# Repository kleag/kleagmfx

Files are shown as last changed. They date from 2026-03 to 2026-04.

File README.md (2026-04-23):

# Kleag's MFX

ADS1115
MCP23017
https://github.com/adafruit/Adafruit-MCP23017-Arduino-Library#pin-addressing

KY-040
n°4 on MCP@0x20
    - sw pin B1 (9)
    - but on A0, B0 (0, 8)

Pisound
Raspberry Pi 5 (4 should be OK)

Joystick: ADS.P0, ADS.P1
sudo apt install python3-uinput
sudo nano /etc/modules
uinput

Expression Pedal: ADS.P2

sudo nano /etc/udev/rules.d/99-uinput.rules
KERNEL=="uinput", SUBSYSTEM=="misc", MODE="0660", GROUP="input"
sudo usermod -a -G input $USER

`/boot/firmware/config.txt`:
```
display_auto_detect=1
dtparam=i2c_arm=on
dtparam=spi=on
dtparam=i2c_arm_baudrate=400000
dtoverlay=
dtoverlay=pisound
dtoverlay=vc4-kms-v3d
usb_max_current_enable=1
```

sudo raspi-config
```

Then go to:
`Interface Options → I2C → Enable → Reboot the Pi.`

```bash
sudo apt install -y i2c-tools
```

```bash
sudo i2cdetect -y 1
```

`/home/gael/.config/systemd/user/multieffect.service`
`/home/gael/.config/systemd/user/default.target.wants/multieffect.service -> /home/gael/.config/systemd/user/multieffect.service`

```ini
[Unit]
Description=Start Guitar Multi-Effect Python Script
After=graphical-session.target

[Service]
ExecStart=python /home/gael/multieffects/multieffect.py
WorkingDirectory=/home/gael
Restart=on-failure

[Install]
WantedBy=default.target
```

```bash
journalctl --user-unit multieffect.service
systemctl --user disable multieffect.service
systemctl --user enable multieffect.service
systemctl --user stop multieffect.service
systemctl --user start multieffect.service
```

# Disable wlan power management 
To avoid losing Wifi unexpectedly, disable its power management. Create `/etc/systemd/system/wifi-fix.service`:

```ini
[Unit]
Description=Disable WiFi Power Management
After=network.target

[Service]
Type=oneshot
ExecStart=/sbin/iwconfig wlan0 power off
RemainAfterExit=yes

[Install]
WantedBy=multi-user.target
```

and then enable the new service:
```bash
sudo systemctl enable wifi-fix.service
sudo systemctl start wifi-fix.service
```

# License

Copyright Gaël de Chalendar, 2025-2026.
This source describes Open Hardware and is licensed under the CERN-OHL-
W v2.
You may redistribute and modify this documentation and make products
using it under the terms of the CERN-OHL-W v2 (https:/cern.ch/cern-ohl).
This documentation is distributed WITHOUT ANY EXPRESS OR IMPLIED
WARRANTY, INCLUDING OF MERCHANTABILITY, SATISFACTORY QUALITY
AND FITNESS FOR A PARTICULAR PURPOSE. Please see the CERN-OHL-W v2
for applicable conditions.
Source location: https://github.com/kleag/kleagmfx
As per CERN-OHL-W v2 section 4.1, should You produce hardware based on
these sources, You must maintain the Source Location visible on the
external case of the Kleag's MFX or other product you make using
this documentation.

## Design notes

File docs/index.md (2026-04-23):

# Kleag's MFX

Thi site describes the multieffect pedal I built using a Raspberry Pi, a Pisound sound card, the Guitarix effects software, a repurposed wooden box and various other parts. I am at version 2.2.1 of the pedal, but just beginning the documentation. 

To start with, here are two images of the current version:

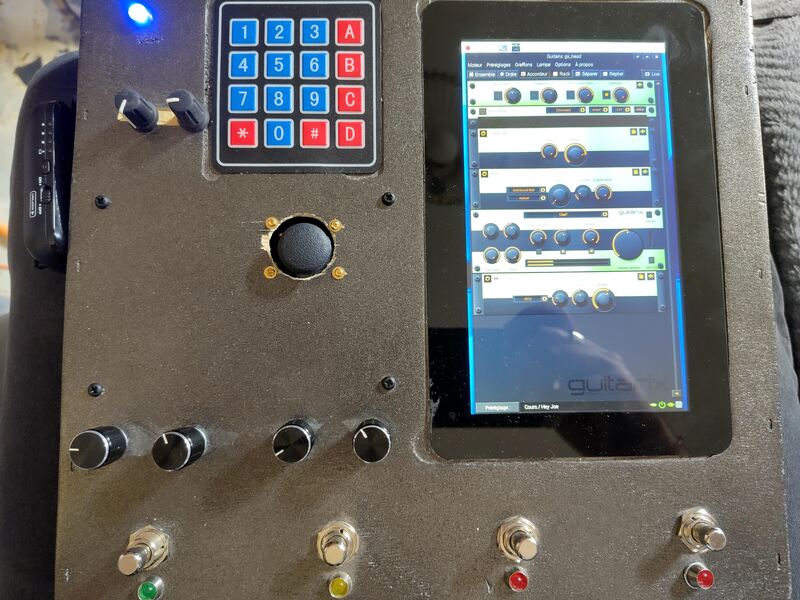
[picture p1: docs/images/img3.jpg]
The Multieffect pedal running


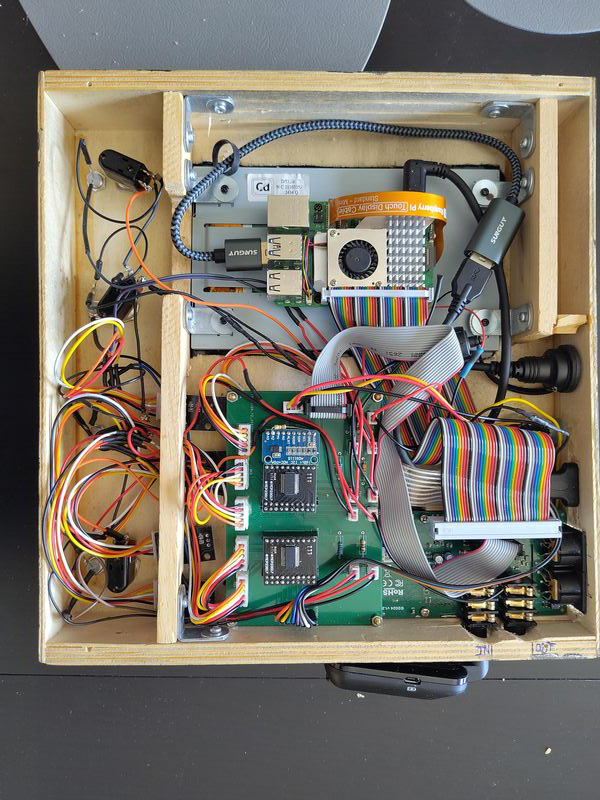
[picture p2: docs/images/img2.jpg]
The interior of the Multieffect pedal


In the future, I will describe the material and software architecture and the history of the making.

ADS1115
MCP23017
https://github.com/adafruit/Adafruit-MCP23017-Arduino-Library#pin-addressing

KY-040
n°4 on MCP@0x20
    - sw pin B1 (9)
    - but on A0, B0 (0, 8)

Pisound
Raspberry Pi 5 (4 should be OK)

Joystick: ADS.P0, ADS.P1
sudo apt install python3-uinput
sudo nano /etc/modules
uinput

Expression Pedal: ADS.P2

sudo nano /etc/udev/rules.d/99-uinput.rules
KERNEL=="uinput", SUBSYSTEM=="misc", MODE="0660", GROUP="input"
sudo usermod -a -G input $USER

`/boot/firmware/config.txt`:
```
display_auto_detect=1
dtparam=i2c_arm=on
dtparam=spi=on
dtparam=i2c_arm_baudrate=400000
dtoverlay=
dtoverlay=pisound
dtoverlay=vc4-kms-v3d
usb_max_current_enable=1
```

sudo raspi-config
```

Then go to:
`Interface Options → I2C → Enable → Reboot the Pi.`

```bash
sudo apt install -y i2c-tools
```

```bash
sudo i2cdetect -y 1
```

`/home/gael/.config/systemd/user/multieffect.service`
`/home/gael/.config/systemd/user/default.target.wants/multieffect.service -> /home/gael/.config/systemd/user/multieffect.service`

```ini
[Unit]
Description=Start Guitar Multi-Effect Python Script
After=graphical-session.target

[Service]
ExecStart=python /home/gael/multieffects/multieffect.py
WorkingDirectory=/home/gael
Restart=on-failure

[Install]
WantedBy=default.target
```

```bash
journalctl --user-unit multieffect.service
systemctl --user disable multieffect.service
systemctl --user enable multieffect.service
systemctl --user stop multieffect.service
systemctl --user start multieffect.service
```

# Disable wlan power management 
To avoid losing Wifi unexpectedly, disable its power management. Create `/etc/systemd/system/wifi-fix.service`:

```ini
[Unit]
Description=Disable WiFi Power Management
After=network.target

[Service]
Type=oneshot
ExecStart=/sbin/iwconfig wlan0 power off
RemainAfterExit=yes

[Install]
WantedBy=multi-user.target
```

and then enable the new service:
```bash
sudo systemctl enable wifi-fix.service
sudo systemctl start wifi-fix.service
```

# License

Copyright Gaël de Chalendar, 2025-2026.
This source describes Open Hardware and is licensed under the CERN-OHL-
W v2.
You may redistribute and modify this documentation and make products
using it under the terms of the CERN-OHL-W v2 (https:/cern.ch/cern-ohl).
This documentation is distributed WITHOUT ANY EXPRESS OR IMPLIED
WARRANTY, INCLUDING OF MERCHANTABILITY, SATISFACTORY QUALITY
AND FITNESS FOR A PARTICULAR PURPOSE. Please see the CERN-OHL-W v2
for applicable conditions.
Source location: https://github.com/kleag/kleagmfx
As per CERN-OHL-W v2 section 4.1, should You produce hardware based on
these sources, You must maintain the Source Location visible on the
external case of the Kleag's MFX or other product you make using
this documentation.

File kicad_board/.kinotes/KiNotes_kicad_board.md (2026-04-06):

# **kicad_board - Design Notes**

## **Overview**
<!-- Brief description of the PCB project -->

## **Schematic Notes**
<!-- Key circuit blocks, design rationale -->

## **Layout Considerations**
<!-- Layer stackup, impedance, keep-outs -->

## **Component Notes**
<!-- Click on designators like R1, C5, U3 to highlight on PCB -->

## **Power Distribution**
<!-- Power rails, decoupling strategy -->

## **Signal Integrity**
<!-- Critical nets, routing constraints -->

## **References**
<!-- Datasheets, application notes, calculations -->

---
*KiNotes - PCBtools.xyz*

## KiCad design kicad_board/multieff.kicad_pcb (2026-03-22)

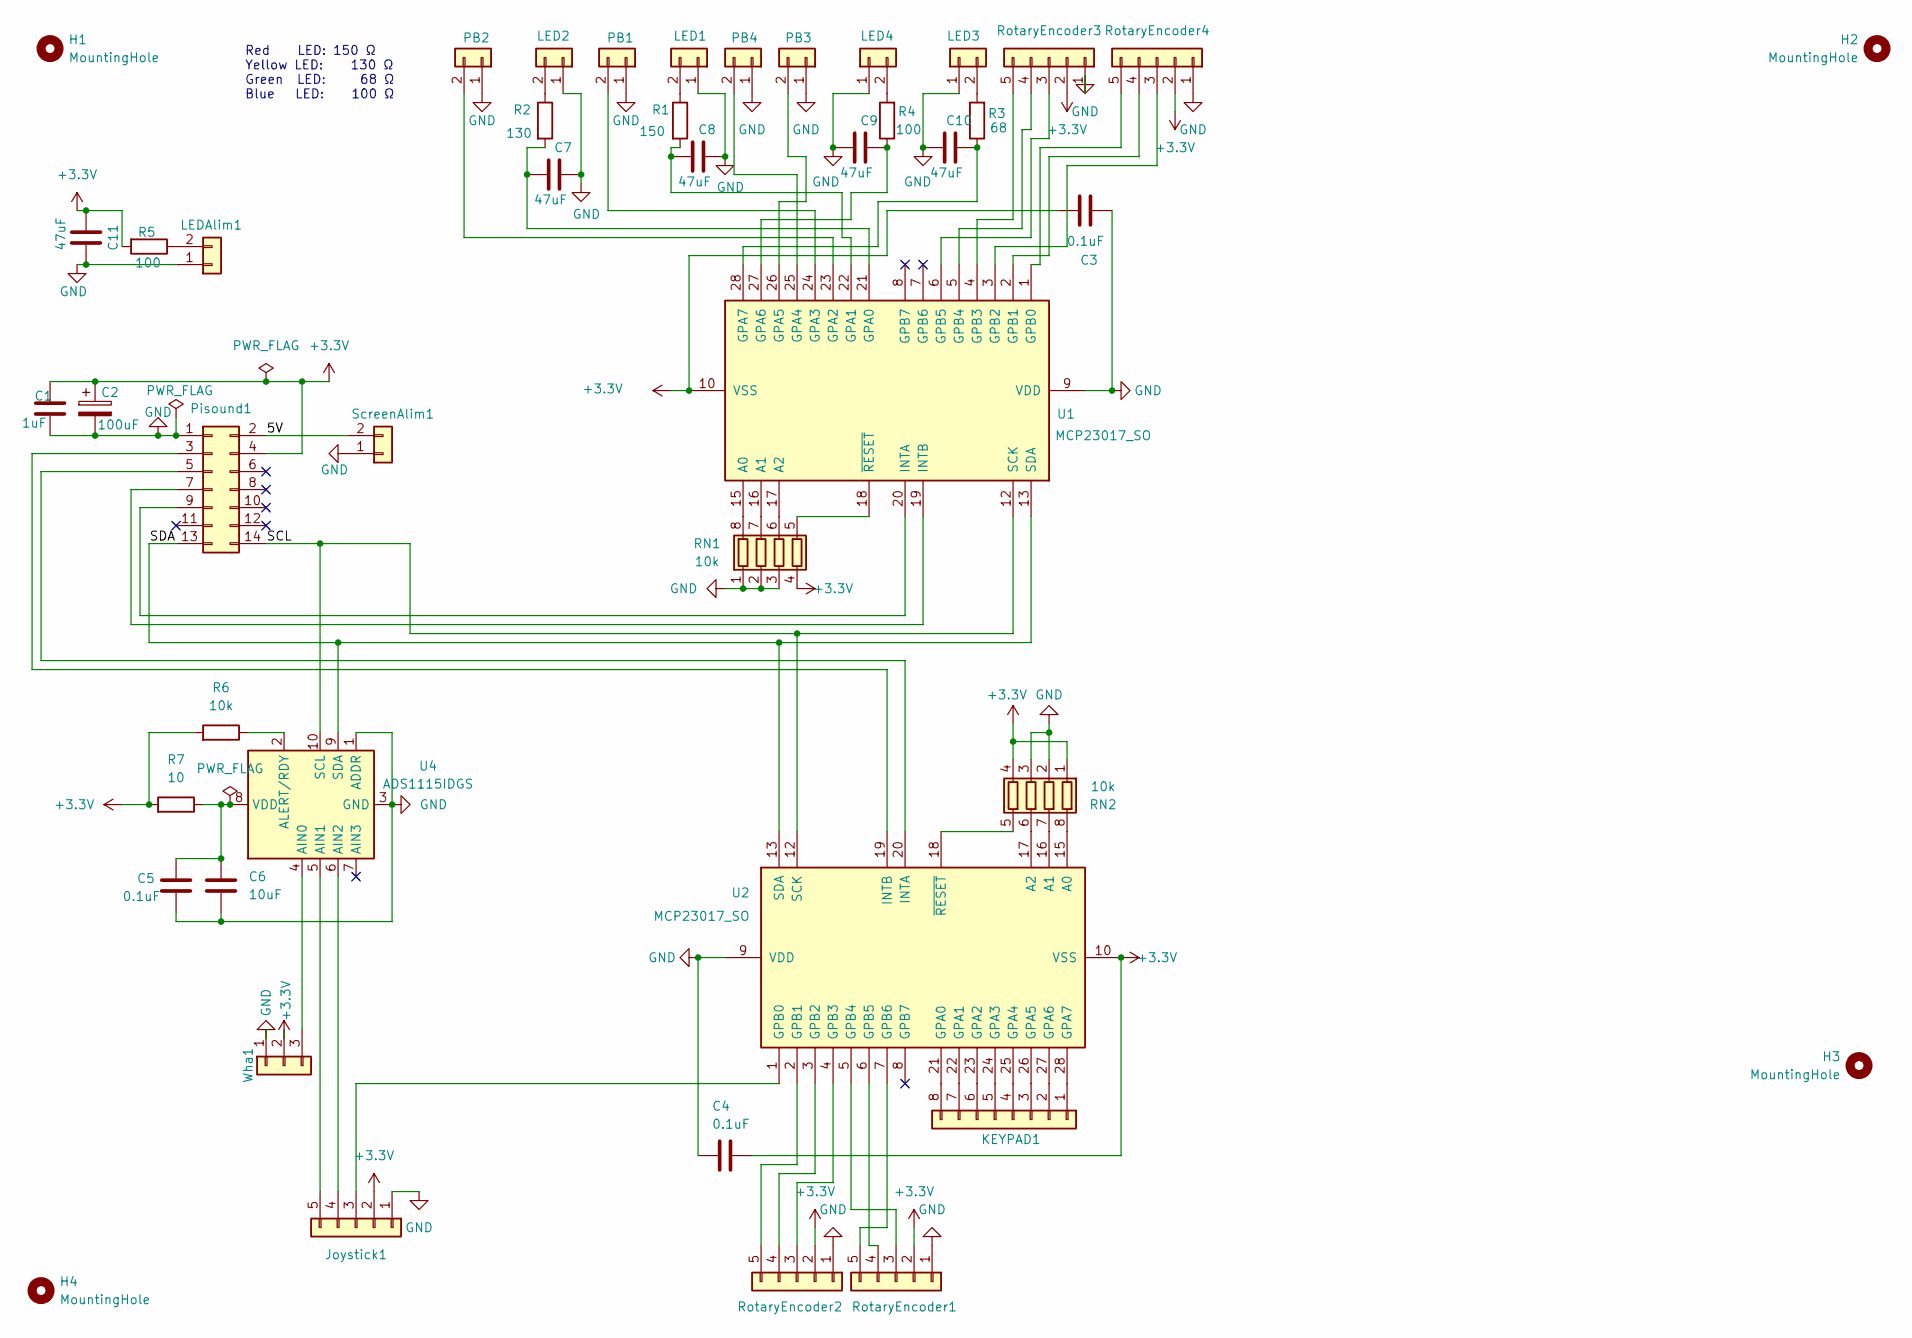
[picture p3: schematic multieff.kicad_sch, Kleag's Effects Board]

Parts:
C1: 1uF; C_0805_2012Metric
C2: 100uF; CP_Elec_6.3x5.4
C3, C4: 0.1uF; C_1206_3216Metric
C5: 0.1uF; C_0805_2012Metric
C6: 10uF; C_0805_2012Metric
C7, C8, C9, C10, C11: 47uF; C_0805_2012Metric
H1, H2, H3, H4: MountingHole; MountingHole_3.2mm_M3
J1: Wha1; JST_XH_B3B-XH-AM_1x03_P2.50mm_Vertical
Joystick1: Conn_01x05; JST_XH_B5B-XH-AM_1x05_P2.50mm_Vertical
KEYPAD1: Conn_01x08; PinSocket_1x08_P2.54mm_Vertical
LED1, LED2, LED3, LED4: Conn_01x02; JST_XH_B2B-XH-AM_1x02_P2.50mm_Vertical
LEDAlim1: Conn_01x02; JST_XH_B2B-XH-AM_1x02_P2.50mm_Vertical
PB1, PB2, PB3, PB4: Conn_01x02; JST_XH_B2B-XH-AM_1x02_P2.50mm_Vertical
Pisound1: Conn_02x07_Odd_Even; IDC-Header_2x07_P2.54mm_Vertical_SMD
R1: 150; R_1206_3216Metric_Pad1.30x1.75mm_HandSolder
R2: 130; R_1206_3216Metric_Pad1.30x1.75mm_HandSolder
R3: 68; R_1206_3216Metric_Pad1.30x1.75mm_HandSolder
R4, R5: 100; R_1206_3216Metric_Pad1.30x1.75mm_HandSolder
R6: 10k; R_0612_1632Metric
R7: 10; R_0612_1632Metric
RN1, RN2: 10k; R_Array_Convex_4x1206
RotaryEncoder1, RotaryEncoder2, RotaryEncoder3, RotaryEncoder4: Conn_01x05; JST_XH_B5B-XH-AM_1x05_P2.50mm_Vertical
ScreenAlim1: Conn_01x02; JST_XH_B2B-XH-AM_1x02_P2.50mm_Vertical
U1, U2: MCP23017_SO; SOIC-28W_7.5x17.9mm_P1.27mm
U4: ADS1115IDGS; TSSOP-10_3x3mm_P0.5mm

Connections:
+3.3V: C1.1, C2.1, C3.2, C4.2, C11.1, J1.2, Joystick1.2, Pisound1.4, R5.2, R6.1, R7.1, RN1.4 (R4.1), RN2.1 (R1.1), RN2.4 (R4.1), RotaryEncoder1.2, RotaryEncoder2.2, RotaryEncoder3.2, RotaryEncoder4.2, U1.10 (VSS), U2.10 (VSS)
/5V: Pisound1.2, ScreenAlim1.2
/SCL: Pisound1.14, U1.12 (SCK), U2.12 (SCK), U4.10 (SCL)
/SDA: Pisound1.13, U1.13 (SDA), U2.13 (SDA), U4.9 (SDA)
GND: C1.2, C2.2, C3.1, C4.1, C5.2, C6.2, C7.2, C8.2, C9.1, C10.1, C11.2, J1.1, Joystick1.1, LED1.1, LED2.1, LED3.1, LED4.1, LEDAlim1.1, PB1.1, PB2.1, PB3.1, PB4.1, Pisound1.1, RN1.1 (R1.1), RN1.2 (R2.1), RN1.3 (R3.1), RN2.2 (R2.1), RN2.3 (R3.1), RotaryEncoder1.1, RotaryEncoder2.1, RotaryEncoder3.1, RotaryEncoder4.1, ScreenAlim1.1, U1.9 (VDD), U2.9 (VDD), U4.1 (ADDR), U4.3 (GND)
unnamed: J1.3, U4.4 (AIN0)
unnamed: Joystick1.3, U2.1 (GPB0)
unnamed: Joystick1.4, U4.6 (AIN2)
unnamed: Joystick1.5, U4.5 (AIN1)
unnamed: KEYPAD1.1, U2.28 (GPA7)
unnamed: KEYPAD1.2, U2.27 (GPA6)
unnamed: KEYPAD1.3, U2.26 (GPA5)
unnamed: KEYPAD1.4, U2.25 (GPA4)
unnamed: KEYPAD1.5, U2.24 (GPA3)
unnamed: KEYPAD1.6, U2.23 (GPA2)
unnamed: KEYPAD1.7, U2.22 (GPA1)
unnamed: KEYPAD1.8, U2.21 (GPA0)
unnamed: LED1.2, R1.1
unnamed: LED2.2, R2.1
unnamed: LED3.2, R3.2
unnamed: LED4.2, R4.2
unnamed: LEDAlim1.2, R5.1
unnamed: PB1.2, U1.24 (GPA3)
unnamed: PB2.2, U1.23 (GPA2)
unnamed: PB3.2, U1.26 (GPA5)
unnamed: PB4.2, U1.25 (GPA4)
unnamed: Pisound1.3, U2.19 (INTB)
unnamed: Pisound1.5, U2.20 (INTA)
unnamed: Pisound1.7, U1.19 (INTB)
unnamed: Pisound1.9, U1.20 (INTA)
unnamed: RN1.8 (R1.2), U1.15 (A0)
unnamed: RN1.7 (R2.2), U1.16 (A1)
unnamed: RN1.6 (R3.2), U1.17 (A2)
unnamed: RN1.5 (R4.2), U1.18 (~RESET)
unnamed: RN2.8 (R1.2), U2.15 (A0)
unnamed: RN2.7 (R2.2), U2.16 (A1)
unnamed: RN2.6 (R3.2), U2.17 (A2)
unnamed: RN2.5 (R4.2), U2.18 (~RESET)
unnamed: RotaryEncoder1.3, U2.5 (GPB4)
unnamed: RotaryEncoder1.4, U2.6 (GPB5)
unnamed: RotaryEncoder1.5, U2.7 (GPB6)
unnamed: RotaryEncoder2.3, U2.4 (GPB3)
unnamed: RotaryEncoder2.4, U2.3 (GPB2)
unnamed: RotaryEncoder2.5, U2.2 (GPB1)
unnamed: RotaryEncoder3.3, U1.6 (GPB5)
unnamed: RotaryEncoder3.4, U1.5 (GPB4)
unnamed: RotaryEncoder3.5, U1.4 (GPB3)
unnamed: RotaryEncoder4.3, U1.3 (GPB2)
unnamed: RotaryEncoder4.4, U1.2 (GPB1)
unnamed: RotaryEncoder4.5, U1.1 (GPB0)
unnamed: C7.1, R2.2, U1.21 (GPA0)
unnamed: C8.1, R1.2, U1.22 (GPA1)
unnamed: C9.2, R4.1, U1.27 (GPA6)
unnamed: C10.2, R3.1, U1.28 (GPA7)
unnamed: R6.2, U4.2 (ALERT/RDY)
unnamed: C5.1, C6.1, R7.2, U4.8 (VDD)

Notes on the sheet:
Red LED: 150 Ω Yellow LED: 130 Ω Green LED: 68 Ω Blue LED: 100 Ω

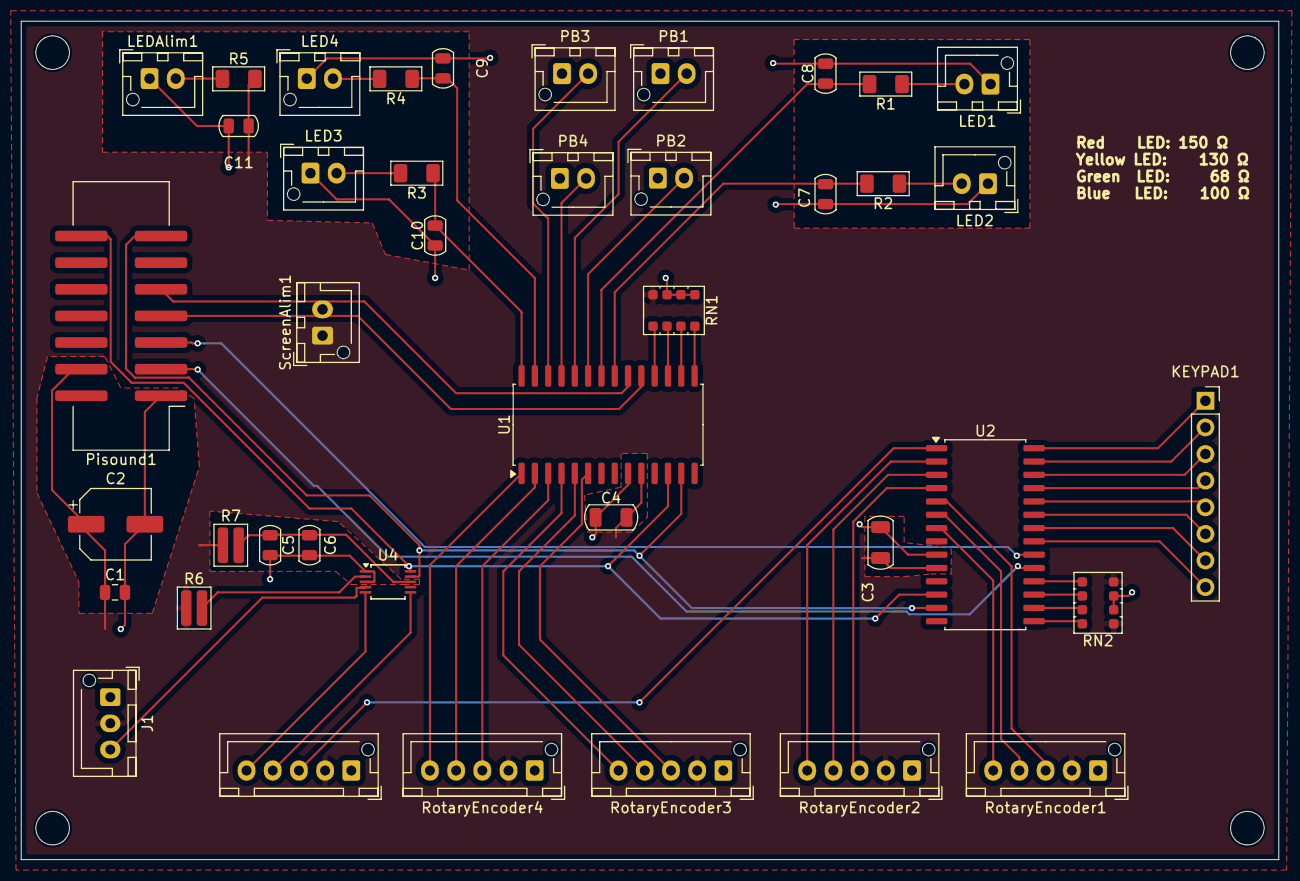
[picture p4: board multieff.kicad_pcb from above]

Board: 2 copper layers, 120.0 x 80.0 mm, 45 parts (0 on the bottom side), 56 nets.

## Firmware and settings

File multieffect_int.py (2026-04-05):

#!/usr/bin/env python3
import adafruit_ads1x15.ads1115 as ADS
import board
import busio
import digitalio
import math
import queue
import time
import uinput
import mido
import logging
import subprocess
import threading

from adafruit_ads1x15.analog_in import AnalogIn
from adafruit_mcp230xx.mcp23017 import MCP23017
from digitalio import Direction, Pull
from gpiozero import Button as GpioZeroButton, LED as GpioZeroLED
from signal import pause

from expression_pedal import ExpressionPedal
from joystick import Joystick
from keypad import KeyPad
from mcp_button import MCPButton
from mcp_led import MCPLed
from rotary_encoder import RotaryEncoder

logger = logging.getLogger(__name__)
logging.basicConfig(level=logging.DEBUG, force=True)

# --- CONFIGURATION ---
SWITCH_CC = 64  # MIDI CC number for effect toggles
ENCODER_CC_NUMBERS = [20, 21, 22, 23]  # MIDI CC for encoders

# Keypad/Power LED (Keep original GPIO)
POWER_LED_PIN = 11

# MCP23017 1 Button/LED Map
BUTTON_PINS_MAP = [(1, 14), (1, 15), (1, 6), (1, 7)] # B6, B7, A6, A7
LED_PINS_MAP = [(1, 13), (1, 12), (1, 4), (1, 5)] # B5, B4, A4, A5

# --- MIDI/ENCODER LOGIC ---
effect_states = [False] * 4 # Global state for MIDI toggles

def send_cc(cc, value):
    msg = mido.Message('control_change', control=cc, value=value)
    midi_out.send(msg)

# --- BUTTON HANDLERS ---
def handle_effect_toggle(idx):
    # logger.info(f"handle_effect_toggle {idx}")
    effect_states[idx] = not effect_states[idx]
    if leds[idx] is not None:
        leds[idx].value = effect_states[idx]
    send_cc(SWITCH_CC + idx, 127 if effect_states[idx] else 0)
    # logger.info(f"Button {idx} pressed. State: {effect_states[idx]}")


def reset():
    logger.info("reset")
    for i in range(len(effect_states)):
        effect_states[i] = False
        if leds[i] is not None:
            leds[i].value = False

# --- THREADS ---

def midi_input_thread():
    # logger.info("Listening for incoming MIDI messages...")
    for msg in midi_in:
        if msg.type == 'control_change':
            # logger.info(f"midi_input_thread received: {msg}")
            # Update Effect States (SWITCH_CC)
            if SWITCH_CC <= msg.control <= SWITCH_CC + 3:
                idx = msg.control - SWITCH_CC
                new_state = msg.value > 0

                # Only update if the state actually changed to avoid flickering
                if effect_states[idx] != new_state:
                    effect_states[idx] = new_state
                    if leds[idx] is not None:
                        leds[idx].value = new_state
                # logger.debug(f"Sync: LED {idx} set to {new_state} via MIDI")
            # Update Encoder CC Value if received externally
            if msg.control in ENCODER_CC_NUMBERS:
                for encoders in [encoders_mcp1, encoders_mcp2]:
                    for enc in encoders:
                        if enc.cc == msg.control:
                            enc.update_from_midi(msg.value)
                            break

def buttons_thread():
    while True:
        # MCP Button Scan
        for i, btn in enumerate(buttons):
            btn.check(i)
        time.sleep(0.01)

# --- Main Thread Logic ---
def main_thread_loop():
    # logger.info("\n[Main Thread] Starting queue processor...")

    while True:
        while not task_queue.empty():
            try:
                func, args = task_queue.get(timeout=0.1)
                if func == "reset":
                    reset(*args)

                task_queue.task_done()
            except queue.Empty:
                # This happens if the queue is temporarily empty
                pass
        time.sleep(0.001)

def link_pipewire_ports():
    try:
        # Link Script -> Guitarix
        subprocess.run(['pw-link', 'Midi-Bridge:RtMidiOut Client:(capture_0) KleagMFX', 'gx_head_amp:midi_in_1'], check=False)
        # Link Guitarix -> Script
        subprocess.run(['pw-link', 'gx_head_amp:midi_out_1', 'Midi-Bridge:RtMidiIn Client:(playback_0) KleagMFX'], check=False)
        logger.info("PipeWire MIDI ports linked successfully.")
    except Exception as e:
        logger.error(f"Failed to link PipeWire ports: {e}")


# --- MIDI SETUP ---
midi_out = mido.open_output('KleagMFX', virtual=True)
midi_in = mido.open_input('KleagMFX', virtual=True)

# --- HARDWARE INITIALIZATION ---
i2c = busio.I2C(board.SCL, board.SDA)
i2c_lock = threading.Lock()

# ADS1115 for Joystick (kept as requested)
ads = ADS.ADS1115(i2c)

# MCP23017
mcp1 = MCP23017(i2c, address=0x20)
mcp2 = MCP23017(i2c, address=0x21)
MCP_MAP = {1: mcp1, 2: mcp2}

# --- Configuration of Interruption pins ---
int_mcp1 = digitalio.DigitalInOut(board.D22) # Pin pisound 7
int_mcp2 = digitalio.DigitalInOut(board.D5)  # Pin pisound 5
for pin in [int_mcp1, int_mcp2]:
    pin.direction = digitalio.Direction.INPUT
    pin.pull = digitalio.Pull.UP

for m in [mcp1, mcp2]:
    m.interrupt_configuration = 0x40 # Mode Mirror : INTA/B linked
    # Activate interruptions on pins used
    # MCP1 : A0, A1, A2, A3 (0x0F) et B0, B1 (0x03)
    # MCP2 : B2-B7 (0xFC)
    if m == mcp1:
        m._write_u8(0x04, 0x0F) # GPINTENA
        m._write_u8(0x05, 0x03) # GPINTENB
    else:
        m._write_u8(0x04, 0x00) # GPINTENA (rien sur port A)
        m._write_u8(0x05, 0xFC) # GPINTENB (B2 à B7)


# Power LED
power_led = mcp1.get_pin(POWER_LED_PIN)
power_led.direction = Direction.OUTPUT
power_led.value = True

# Foot switches and their associated LED
buttons = [MCPButton(MCP_MAP[mcp], pin) for mcp, pin in BUTTON_PINS_MAP]
leds = [MCPLed(MCP_MAP[mcp], pin) for mcp, pin in LED_PINS_MAP]

# Board label: as visible on physical pedalboard: mcp number and mcp pins map
# RotaryEncoder4: 1st from left to right above : mcp n°2 clk B4=12 dt B3=11 sw B2=10
# RotaryEncoder3: 2nd from left to right above : mcp n°2 clk B7=15 dt B6=14 sw B5=13
# RotaryEncoder2: 3rd from left to right above : mcp n°1 clk A3=3  dt A2=2  sw A1=1
# RotaryEncoder1: 4th from left to right above : mcp n°1 clk A0=0, dt B0=8, sw B1=9
# --- ROTARY ENCODERS ---
encoder_configs = [
    (mcp1, 0,   8,  9, "Encoder 0", ENCODER_CC_NUMBERS[0]), # CC 20
    (mcp1, 3,   2,  1, "Encoder 1", ENCODER_CC_NUMBERS[1]), # CC 21
    (mcp2, 15, 14, 13, "Encoder 2", ENCODER_CC_NUMBERS[2]), # CC 22
    (mcp2, 12, 11, 10, "Encoder 3", ENCODER_CC_NUMBERS[3]), # CC 23
]
encoders_mcp1 = []
encoders_mcp2 = []
for mcp, clk_pin, dt_pin, sw_pin, name, cc in encoder_configs:
    encoder = RotaryEncoder(midi_out, mcp, name, clk_pin, dt_pin, sw_pin, cc)
    if mcp == mcp1:
        encoders_mcp1.append(encoder)
    else:
        encoders_mcp2.append(encoder)
    buttons.append(encoder.button)
    effect_states.append(False)
    leds.append(None)

def watchdog_thread():
    while True:
        if not int_mcp1.value:
            data = mcp1.gpio
            for enc in encoders_mcp1:
                enc.update(data)

        if not int_mcp2.value:
            data = mcp2.gpio
            for enc in encoders_mcp2:
                enc.update(data)

        time.sleep(0.001)

for i, btn in enumerate(buttons):
    btn.when_pressed = handle_effect_toggle


# === Main ===
if __name__ == "__main__":
    link_pipewire_ports()
    task_queue = queue.Queue()
    joystick = Joystick(ads, mcp1, lock=i2c_lock)
    keypad = KeyPad(task_queue, midi_out, mcp2)
    pedal = ExpressionPedal(midi_out, ads, lock=i2c_lock, channel=ADS.P2)

    threading.Thread(target=midi_input_thread, daemon=True).start()
    threading.Thread(target=buttons_thread, daemon=True).start()
    threading.Thread(target=joystick.poll_joystick, daemon=True).start()
    threading.Thread(target=keypad.keypad_thread, daemon=True).start()
    threading.Thread(target=pedal.poll, daemon=True).start()
    threading.Thread(target=watchdog_thread, daemon=True).start()

    # for encoder in encoders:
    #     threading.Thread(target=encoder.poll_thread, daemon=True).start()
    threading.Thread(target=main_thread_loop, daemon=True).start()

    logger.info("Kleag's Multi-effect daemon running.")
    try:
        pause()
    except KeyboardInterrupt:
        logger.info("Kleag's Multi-effect daemon terminating through keyboard interrupt.")

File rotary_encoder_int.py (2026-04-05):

#!/usr/bin/env python3
import digitalio
import time
import mido
import logging

from adafruit_mcp230xx.mcp23017 import MCP23017
from digitalio import Direction, Pull
from signal import pause

from mcp_button import MCPButton

logger = logging.getLogger(__name__)

# --- CONFIGURATION ---

ENCODER_STEP = 5  # Value change per encoder tick (approx. 5% of 127)
SWITCH_CC = 64  # MIDI CC number for effect toggles

class RotaryEncoder:
    # 4. Define Valid Transitions (Standard Quadrature Sequence)
    # Clockwise (CW) steps:
    # 00 -> 10 (0x2)
    # 10 -> 11 (0xB)
    # 11 -> 01 (0x7)
    # 01 -> 00 (0x4)
    CW_transitions = {0b0010, 0b1011, 0b1101, 0b0100} # Set of 4-bit transition keys

    # Counter-Clockwise (CCW) steps (Reversed Sequence):
    # 00 -> 01 (0x1)
    # 01 -> 11 (0x7) -> NOTE: 0x7 (1101) is CCW, 0x7 (0111) is CW
    # Let's list the CCW sequences explicitly:
    # 00 -> 01 (0x1)
    # 01 -> 11 (0x7)
    # 11 -> 10 (0xE)
    # 10 -> 00 (0x8)
    CCW_transitions = {0b0001, 0b0111, 0b1110, 0b1000}

    def __init__(self, midi_out, mcp: MCP23017, name: str, clk_pin: int, dt_pin: int, sw_pin: int, cc: int):
        logger.info(f"RotaryEncoder {name}, clk: {clk_pin}, dt: {dt_pin}, sw: {sw_pin}, cc: {cc}")
        self.midi_out = midi_out
        self.clk = mcp.get_pin(clk_pin)
        self.dt = mcp.get_pin(dt_pin)
        self.clk_num = clk_pin
        self.dt_num = dt_pin
        self.sw_num = sw_pin
        initial_clk = self.clk.value
        initial_dt = self.dt.value
        for pin in (self.clk, self.dt):
            pin.direction = Direction.INPUT
            pin.pull = Pull.UP

        self.name = name,
        self.cc = cc
        # self.sw = sw
        self.last_clk = 1
        self.last_state = (initial_clk << 1) | initial_dt
        # self.last_sw = sw.value
        self.midi_value = SWITCH_CC
        self.button = MCPButton(mcp, sw_pin)
        self.button.when_pressed = self.button_pressed
        self.send_cc(self.midi_value)


    def button_pressed(self):
        logger.debug(f"RotaryEncoder {self.name} button_pressed")


    def update_from_midi(self, value):
        """External sync: Updates the internal value without sending a MIDI msg."""
        if 0 <= value <= 127:
            self.midi_value = value
            logger.debug(f"{self.name} synced to {value}")

    def update(self, gpio_state):
        current_clk = (gpio_state >> self.clk_num) & 0x01
        current_dt = (gpio_state >> self.dt_num) & 0x01
        current_sw = (gpio_state >> self.sw_num) & 0x01

        changed = False
        # Détection de rotation (Falling edge sur CLK)
        if current_clk != self.last_clk and current_clk == 0:
            if current_dt != current_clk:
                direction = 1
                # logger.info(f"{encoder['name']} turned {direction}, send to {encoder['cc']}")
            else:
                direction = -1
            cc_value = self.increment_cc_value(direction)
            logger.debug(f"{self.name} [CC{self.cc}]: {cc_value}")
            changed = True

        if current_sw == 0:
            # Note : à filtrer avec un timer si vous voulez éviter les répétitions
            pass

        self.last_clk = current_clk
        return changed

    def read_encoder_state_machine(self):

        # 1. Read Current State (2-bit value: (clk << 1) | dt)
        current_clk = int(self.clk.value)
        # print(type(current_clk), current_clk)
        current_dt = int(self.dt.value)
        current_state = (current_clk << 1) | current_dt # e.g., 00, 01, 10, or 11

        # 2. Check if the state has changed
        if current_state != self.last_state:

            # 3. Create a 4-bit transition key: (last_state << 2) | current_state
            # This key defines the exact transition, e.g., 00 -> 10, or 10 -> 11
            transition = (self.last_state << 2) | current_state

            # 5. Check if the transition is valid and update
            if transition in RotaryEncoder.CW_transitions:
                # logger.debug(f"Encoder {self.name} Rotated → (clockwise)")
                self.last_state = current_state # Update state after a valid step
                direction = 1
                # logger.info(f"{encoder['name']} turned {direction}, send to {encoder['cc']}")
                self.increment_cc_value(direction)

            elif transition in RotaryEncoder.CCW_transitions:
                # logger.debug(f"Encoder {self.name} Rotated → (counterclockwise)")
                self.last_state = current_state # Update state after a valid step
                direction = -1
                # logger.debug(f"{encoder['name']} turned {direction}, send to {encoder['cc']}")
                self.increment_cc_value(direction)

            # 6. Optional: If the transition is invalid (i.e., due to bounce/noise),
            #    we generally ignore it and wait for a valid state.
            #    However, if we are in a state not part of the sequence,
            #    we might reset the state to catch up. For simplicity, we only
            #    update the state on a valid transition.
            else:
                # 5. CATCH-UP LOGIC: If the transition is INVALID (due to bounce or skipped steps),
                #    we force the last_state to the current_state.
                #    This ignores the current invalid movement but prepares the encoder
                #    to detect the next valid step from the new physical position.
                # logger.debug(f"Encoder {encoder['name']} state corrected (Invalid transition: {bin(transition)})")
                self.last_state = current_state
            # The key is to only update last_state *after* a valid transition has completed.

    def send_cc(self, value):
        # logger.info(f"RotaryEncoder.send_cc {self.name}: {self.cc}, {value}")
        msg = mido.Message('control_change', control=self.cc, value=value)
        self.midi_out.send(msg)

    def increment_cc_value(self, direction):
        """Adjusts the MIDI CC value for an encoder incrementally."""
        current_value = self.midi_value
        # Adjust by ENCODER_STEP, then clamp
        new_value = max(0, min(127, current_value + direction * ENCODER_STEP))
        if new_value != current_value:
            self.midi_value = new_value
            self.send_cc(new_value)
            logger.debug(f"{self.name} CC {self.cc} adjusted to {new_value}")
        return new_value

    def poll_thread(self):
        while True:
            self.read_encoder_state_machine()
            time.sleep(0.001)
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

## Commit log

2025-10-10 Ignore generated files
    [multieff.kicad_pcb, multieff.kicad_sch]
2025-10-16 Latest pcb version
    [multieff.kicad_pcb, multieff.kicad_sch]
2025-10-17 Add button to joystick test
2025-10-17 Add tests for keypads and leds
2025-10-18 Correct keypad test code
    [keypad_test.py]
2025-10-18 Correct pin numbers
2025-10-19 Give up with interrupts
2025-12-12 Clicking the joystick switch for midi learn works
2025-12-14 Rotary encoders switch added to buttons
2025-12-14 Use the correct mcp for joystick
    [joystick.py, multieffect.py]
2025-12-14 Add classes for KeyPad and Rotary encoders
2025-12-14 Communicate between threads with a queue
2025-12-21 * and # keypad keys are L and R mouse buttons
2025-12-29 Correct mouse buttons clicking implementation
    [keypad.py]
2026-02-15 Add connector for expression pedal
    [multieff.kicad_pcb, multieff.kicad_sch]
2026-02-15 Add component numbering
    [multieff.kicad_sch]
2026-02-15 With zones and jst connectors
    [multieff.kicad_pcb, multieff.kicad_sch]
2026-02-15 Sent to production
    [multieff.kicad_pcb]
2026-03-02 Correct traces geometry
    [multieff.kicad_pcb]
2026-03-02 Improve connectors placement
    [multieff.kicad_pcb, multieff.kicad_sch]
2026-03-03 First mcp23017 chip schema
    [multieff.kicad_sch]
2026-03-04 Ongoing work
    [multieff.kicad_pcb, multieff.kicad_sch]
2026-03-04 Work in progress
    [multieff.kicad_pcb, multieff.kicad_sch]
2026-03-05 First complete IC based version
    Still miss some decoupling condensators.
    [multieff.kicad_pcb, multieff.kicad_sch]
2026-03-06 Chips decoupling complete
    [multieff.kicad_pcb, multieff.kicad_sch]
2026-03-06 Add decoupling capacitors to LEDs
    [multieff.kicad_pcb, multieff.kicad_sch]
2026-03-22 Add missing screen alim connector
    [multieff.kicad_pcb, multieff.kicad_sch]
2026-03-22 Update rotary encoder tests
2026-04-05 Rotary encoders work
2026-04-05 Add support for expression pedal
    Needed to add lock on joystick i2c read to avoid conflicts.
    [expression_pedal.py, joystick.py, multieffect.py]
2026-04-05 Rotary encoders interruption based work
2026-04-05 Work on interruption based rotary encoders
2026-04-06 Add notes to the board
2026-04-23 Correct expression pedal settings
    [expression_pedal.py]

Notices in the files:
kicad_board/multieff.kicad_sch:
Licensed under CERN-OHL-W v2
